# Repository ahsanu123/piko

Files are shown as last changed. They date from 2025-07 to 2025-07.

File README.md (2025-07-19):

<h1>🐤 piko </h1>
<p>
  <a href="">
    
  </a>
  <a href="">
    
  </a>
  <a href="">
    
  </a>
  <a href="https://github.com/ahsanu123/piko/blob/main/LICENSE">
    
  </a>
</p>

<p align="center">    
  
</p>

<p align="center">CMSIS DAP Probe</p>

### 🧺 Schematic

schematic

## Reference

- make new project Piko, picoprobe based on https://github.com/ErichStyger/mcuoneclipse/tree/master/KiCAD/Projects/PicoLink
- wagiminator ch552 daplink https://github.com/wagiminator/CH552-DAPLink
- yapicoprobe https://github.com/rgrr/yapicoprobe/blob/master/doc/hardware.adoc
- mcu on eclipse picolink https://mcuoneclipse.com/2023/04/08/open-source-picolink-raspberry-pi-rp2040-cmsis-dap-debug-probe/

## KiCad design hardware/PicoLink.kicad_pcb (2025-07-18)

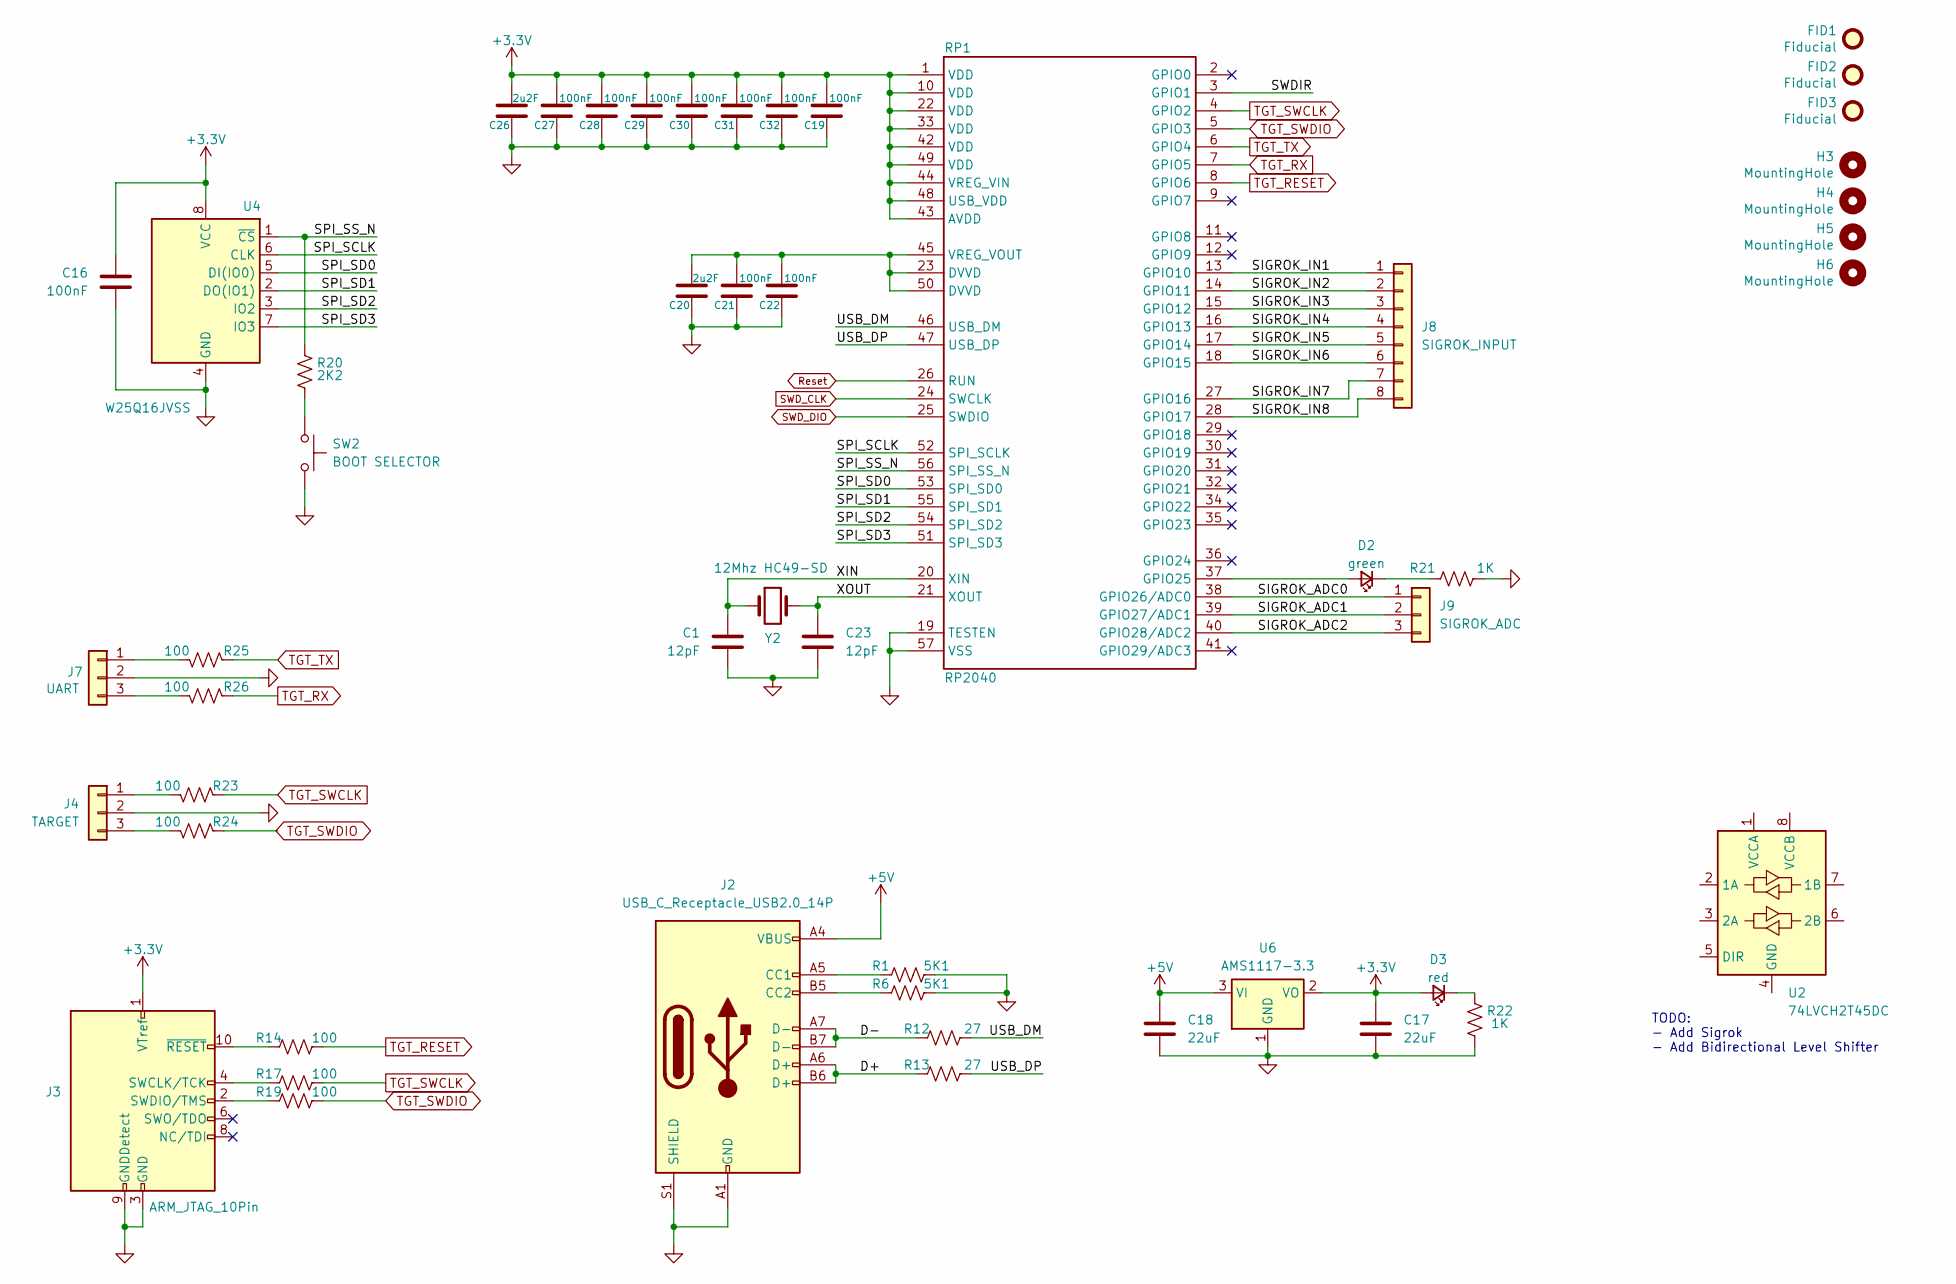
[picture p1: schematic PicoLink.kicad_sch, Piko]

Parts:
C1, C23: 12pF; C_0603_1608Metric_Pad1.08x0.95mm_HandSolder
C16, C19, C21, C22, C27, C28, C29, C30, C31, C32: 100nF; C_0603_1608Metric_Pad1.08x0.95mm_HandSolder
C17, C18: 22uF; C_0603_1608Metric_Pad1.08x0.95mm_HandSolder
C20, C26: 2u2F; C_0603_1608Metric_Pad1.08x0.95mm_HandSolder
D2: green; LED_0805_2012Metric_Pad1.15x1.40mm_HandSolder; mouser# 78-VLMTG1300-GS08
D3: red; LED_0805_2012Metric_Pad1.15x1.40mm_HandSolder; mouser# 78-VLMS1300-GS08
FID1, FID2, FID3: Fiducial; Fiducial_1mm_Mask2mm
H3, H4, H5, H6: MountingHole; MountingHole_2.7mm_M2.5
J2: USB_C_Receptacle_USB2.0_14P; USB_C_Receptacle_GCT_USB4110
J3: ARM_JTAG_10Pin; IDC-Header_2x05_P2.54mm_Vertical
J4: TARGET; PinHeader_1x03_P2.54mm_Vertical
J7: UART; PinHeader_1x03_P2.54mm_Vertical
J8: SIGROK_INPUT; PinHeader_1x07_P2.54mm_Vertical
J9: SIGROK_ADC; PinHeader_1x03_P2.54mm_Vertical
R1, R6: 5K1; R_0805_2012Metric_Pad1.20x1.40mm_HandSolder
R12, R13: 27; R_0805_2012Metric_Pad1.20x1.40mm_HandSolder
R14, R17, R19, R23, R24, R25, R26: 100; R_0805_2012Metric_Pad1.20x1.40mm_HandSolder
R20: 2K2; R_0805_2012Metric_Pad1.20x1.40mm_HandSolder
R21, R22: 1K; R_0805_2012Metric_Pad1.20x1.40mm_HandSolder
RP1: RP2040; QFN-56-1EP_7x7mm_P0.4mm_EP3.2x3.2mm; MFR# RPI Chip RP2040-7-500; mouser# 358-RP2040CHIP-7-500
SW2: BOOT SELECTOR; SW_Push_1P1T_NO_6x6mm_H9.5mm
U2: 74LVCH2T45DC; VSSOP-8_2.3x2mm_P0.5mm
U4: W25Q16JVSS; SOIC-8_5.23x5.23mm_P1.27mm
U6: AMS1117-3.3; SOT-223-3_TabPin2
Y2: 12Mhz HC49-SD; Crystal_SMD_HC49-SD_HandSoldering

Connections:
+3.3V: C16.1, C17.1, C19.1, C26.1, C27.1, C28.1, C29.1, C30.1, C31.1, C32.1, D3.2 (A), J3.1 (VTref), RP1.1 (VDD), RP1.10 (VDD), RP1.22 (VDD), RP1.33 (VDD), RP1.42 (VDD), RP1.43 (AVDD), RP1.44 (VREG_VIN), RP1.48 (USB_VDD), RP1.49 (VDD), U4.8 (VCC), U6.2 (VO)
+5V: C18.1, J2.A4 (VBUS), J2.A9 (VBUS), J2.B4 (VBUS), J2.B9 (VBUS), U6.3 (VI)
/D+: J2.A6 (D+), J2.B6 (D+), R13.1
/D-: J2.A7 (D-), J2.B7 (D-), R12.1
/SIGROK_ADC0: J9.1, RP1.38 (GPIO26/ADC0)
/SIGROK_ADC1: J9.2, RP1.39 (GPIO27/ADC1)
/SIGROK_ADC2: J9.3, RP1.40 (GPIO28/ADC2)
/SIGROK_IN1: J8.1, RP1.13 (GPIO10)
/SIGROK_IN2: J8.2, RP1.14 (GPIO11)
/SIGROK_IN3: J8.3, RP1.15 (GPIO12)
/SIGROK_IN4: J8.4, RP1.16 (GPIO13)
/SIGROK_IN5: J8.5, RP1.17 (GPIO14)
/SIGROK_IN6: J8.6, RP1.18 (GPIO15)
/SIGROK_IN7: J8.7, RP1.27 (GPIO16)
/SIGROK_IN8: J8.8, RP1.28 (GPIO17)
/SPI_SCLK: RP1.52 (SPI_SCLK), U4.6 (CLK)
/SPI_SD0: RP1.53 (SPI_SD0), U4.5 (DI(IO0))
/SPI_SD1: RP1.55 (SPI_SD1), U4.2 (DO(IO1))
/SPI_SD2: RP1.54 (SPI_SD2), U4.3 (IO2)
/SPI_SD3: RP1.51 (SPI_SD3), U4.7 (IO3)
/SPI_SS_N: R20.1, RP1.56 (SPI_SS_N), U4.1 (~CS)
/SWDIR: RP1.3 (GPIO1)
/USB_DM: R12.2, RP1.46 (USB_DM)
/USB_DP: R13.2, RP1.47 (USB_DP)
/XIN: C1.1, RP1.20 (XIN), Y2.1
/XOUT: C23.1, RP1.21 (XOUT), Y2.2
GND: C1.2, C16.2, C17.2, C18.2, C19.2, C20.2, C21.2, C22.2, C23.2, C26.2, C27.2, C28.2, C29.2, C30.2, C31.2, C32.2, J2.A1 (GND), J2.A12 (GND), J2.B1 (GND), J2.B12 (GND), J2.S1 (SHIELD), J3.3 (GND), J3.5 (GND), J3.9 (GNDDetect), J4.2, J7.2, R1.2, R6.2, R21.2, R22.2, RP1.19 (TESTEN), RP1.57 (VSS), SW2.2, U4.4 (GND), U6.1 (GND)
unnamed: D2.2 (A), RP1.37 (GPIO25)
unnamed: D2.1 (K), R21.1
unnamed: D3.1 (K), R22.1
unnamed: J2.A5 (CC1), R1.1
unnamed: J2.B5 (CC2), R6.1
unnamed: J3.4 (SWCLK/TCK), R17.1
unnamed: J3.2 (SWDIO/TMS), R19.1
unnamed: J3.10 (~RESET), R14.1
unnamed: J4.1, R23.2
unnamed: J4.3, R24.2
unnamed: J7.1, R25.2
unnamed: J7.3, R26.2
unnamed: R20.2, SW2.1
unnamed: C20.1, C21.1, C22.1, RP1.23 (DVVD), RP1.45 (VREG_VOUT), RP1.50 (DVVD)
Reset: RP1.26 (RUN)
SWD_CLK: RP1.24 (SWCLK)
SWD_DIO: RP1.25 (SWDIO)
TGT_RESET: R14.2, RP1.8 (GPIO6)
TGT_RX: R26.1, RP1.7 (GPIO5)
TGT_SWCLK: R17.2, R23.1, RP1.4 (GPIO2)
TGT_SWDIO: R19.2, R24.1, RP1.5 (GPIO3)
TGT_TX: R25.1, RP1.6 (GPIO4)

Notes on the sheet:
TODO: - Add Sigrok - Add Bidirectional Level Shifter

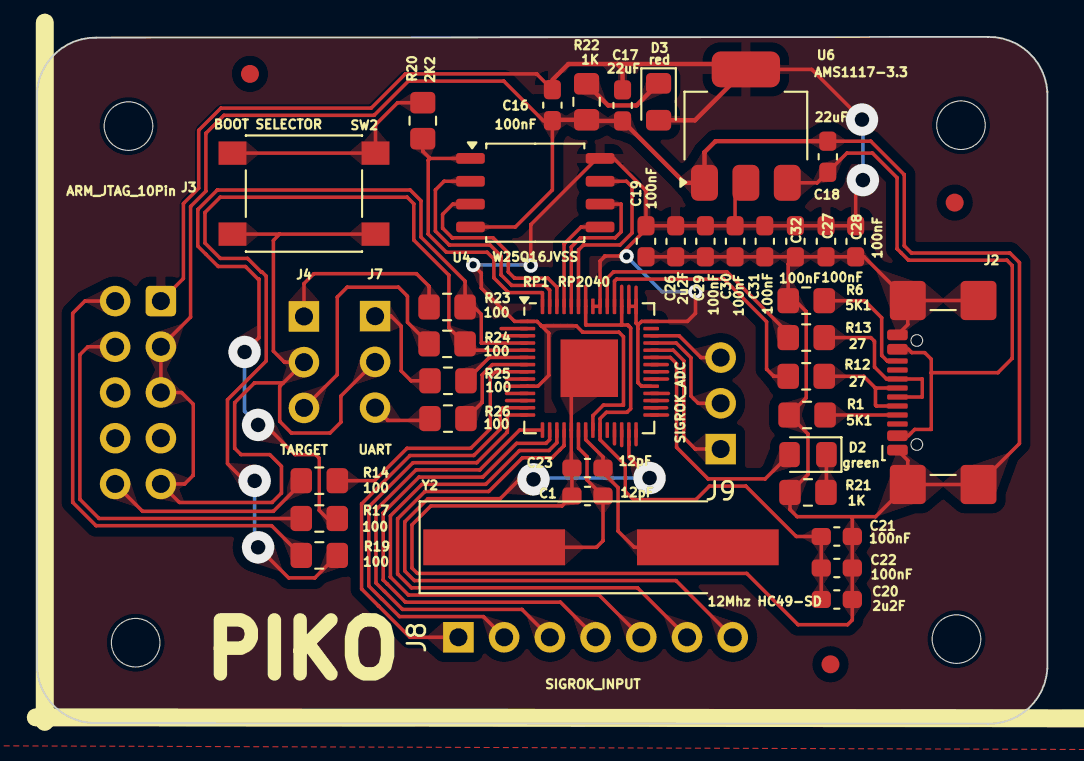
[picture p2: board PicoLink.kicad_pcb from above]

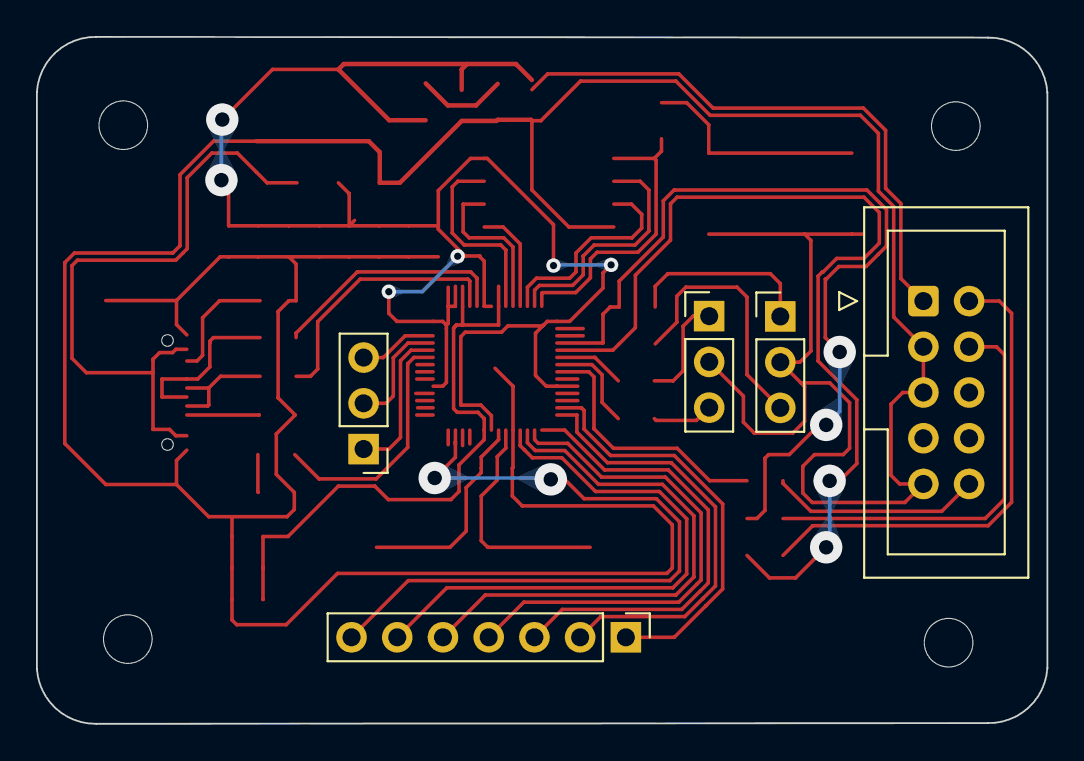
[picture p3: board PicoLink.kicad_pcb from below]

Board: 2 copper layers, 56.1 x 38.2 mm, 50 parts (5 on the bottom side), 44 nets.

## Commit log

2025-07-15 [07-15-1901] piko initial commit
    update
    [PicoLink.kicad_pcb, PicoLink.kicad_sch]
2025-07-16 [07-16-1503] small update on schematic
    [PicoLink.kicad_sch]
2025-07-16 [07-16-2030] finish rough routing
    [PicoLink.kicad_pcb, PicoLink.kicad_sch]
2025-07-17 [07-17-1304] add edge cut
    Update README.md
    [PicoLink.kicad_pcb, PicoLink.kicad_sch]
2025-07-17 [07-17-1556] update silkscreen
    [PicoLink.kicad_pcb]
2025-07-17 [07-17-1645] generate gerber files
    [PicoLink-B_Adhesive.gbr, PicoLink-B_Courtyard.gbr, PicoLink-B_Cu.gbr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]
2025-07-18 [07-18-0738] fabricate pcb
2025-07-18 [07-18-2108] add svg schematic
    [PicoLink.kicad_pcb, PicoLink.kicad_sch]
